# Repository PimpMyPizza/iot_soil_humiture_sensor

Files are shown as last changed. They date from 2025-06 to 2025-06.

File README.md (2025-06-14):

# Connected Humidity and Temperature Sensors

This is a simple MicroPython project to read soil humidity and temperature sensor data using a Raspberry Pi Pico W. It sends the data over MQTT to be integrated with [Home Assistant](https://www.home-assistant.io/).

## What You'll Need

- A Raspberry Pi Pico W (not tested on Pico W 2)
- A soil moisture/humidity sensor (I used an old HD-38 analog sensor)
- A DS18B20 temperature sensor (I used the waterproof version)
- A micro USB cable for power
- (Optional) An NPN transistor (e.g., BC337-40) to switch the moisture sensor off when not in use, extending its lifespan

## Wiring

| Component/Connection | Pico W Pin | Notes |
| --- | --- | --- |
| HD-38 + (VCC) | 3V3 (Pin 36) | Power supply for the moisture sensor |
| HD-38 - (GND) | Collector of NPN | Controlled ground connection |
| HD-38 AO (Analog Output) | GP26 / ADC0 (Pin 31) | Analog input for moisture level |
| NPN Emitter | Pico W GND | Common ground |
| NPN Base | GPIO15 (Pin 20) | Controls the moisture sensor power |
| DS18B20 VCC | GPIO17 (Pin 22) | Switched power for DS18B20 |
| DS18B20 GND | Pico W GND | Common ground |
| DS18B20 Data | GPIO16 (Pin 21) | One-wire data line |
| 4.7kΩ Pull-up Resistor | Between Data & VCC | Required for DS18B20 |

## Uploading the Code to the Pico W

1. Flash the MicroPython .uf2 file onto your Pico W, as described in the [official MicroPython documentation](https://micropython.org/download/RPI_PICO_W/).
2. Use mpremote (or another tool) to copy files and run the script:
```bash
mpremote connect /dev/ttyACM0 \
  fs mkdir src \
  fs cp src/*.py :src/ \
  fs mkdir res \
  fs cp res/*.tmpl :res/ \
  fs cp main.py :main.py
```

## Initial Device Setup

On first boot, the device cannot connect to Wi-Fi unless you’ve preconfigured settings in `src/constants.py`. It will enter Access Point mode and serve a configuration page at http://192.168.4.1.

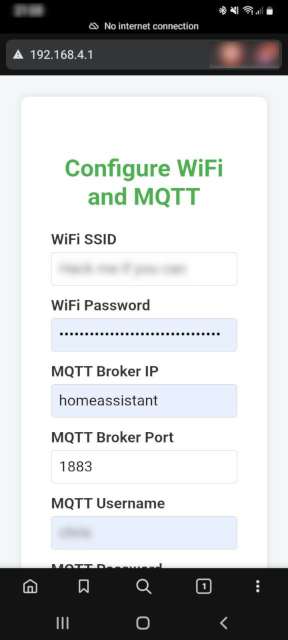
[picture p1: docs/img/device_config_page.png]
Device Configuration Page


1. Connect your phone or laptop to the device's Wi-Fi.
2. Open http://192.168.4.1 in a browser.
3. Enter/Adapt:
    - Wi-Fi SSID and password
    - MQTT broker address, username, and password
    - Measurement frequency
4. Click Save.

The device will remain in AP mode until it can successfully connect to Wi-Fi and the MQTT broker with valid credentials.

## Integrating with Home Assistant

Once connected, the device will send an MQTT discovery message.
1. In Home Assistant, go to Settings > Devices & Services.
2. In the Devices tab, a new device should appear.
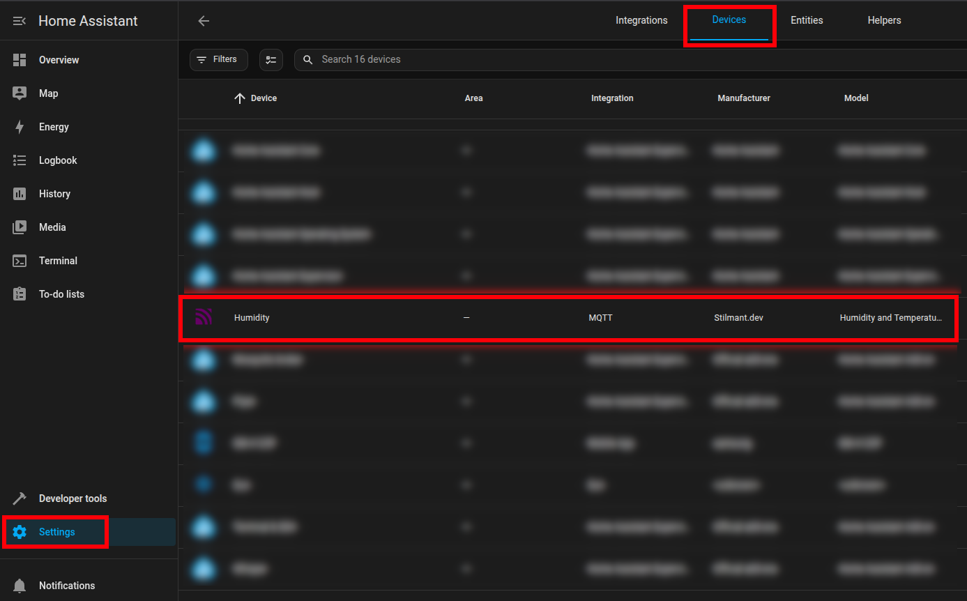
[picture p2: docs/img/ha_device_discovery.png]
Device Configuration Page

3. Click the device to view and add sensors to your dashboard.
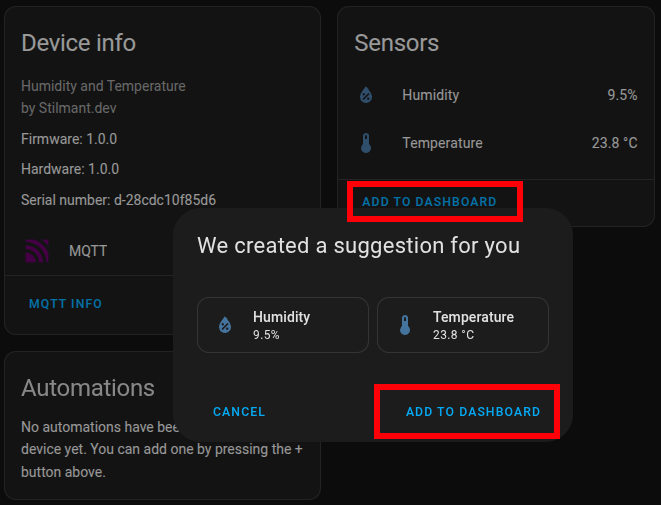
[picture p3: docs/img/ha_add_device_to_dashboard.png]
Device Configuration Page


And that’s it! Your soil humidity and temperature sensor is now connected to Home Assistant.

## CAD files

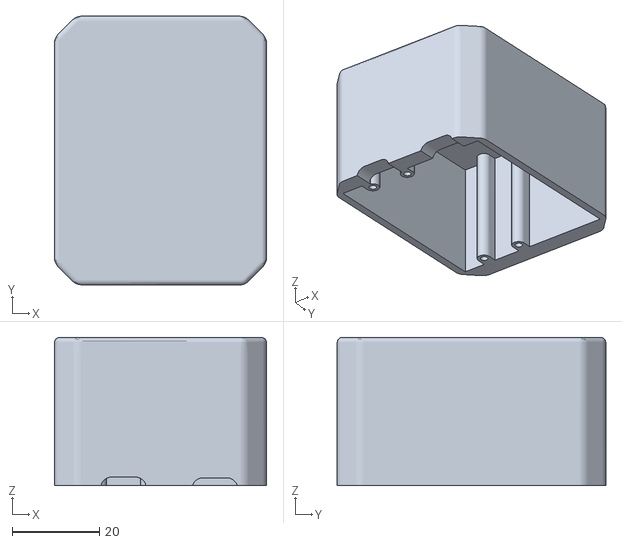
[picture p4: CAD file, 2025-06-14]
cad/case_top.stl
48.7 x 61.7 x 34.0

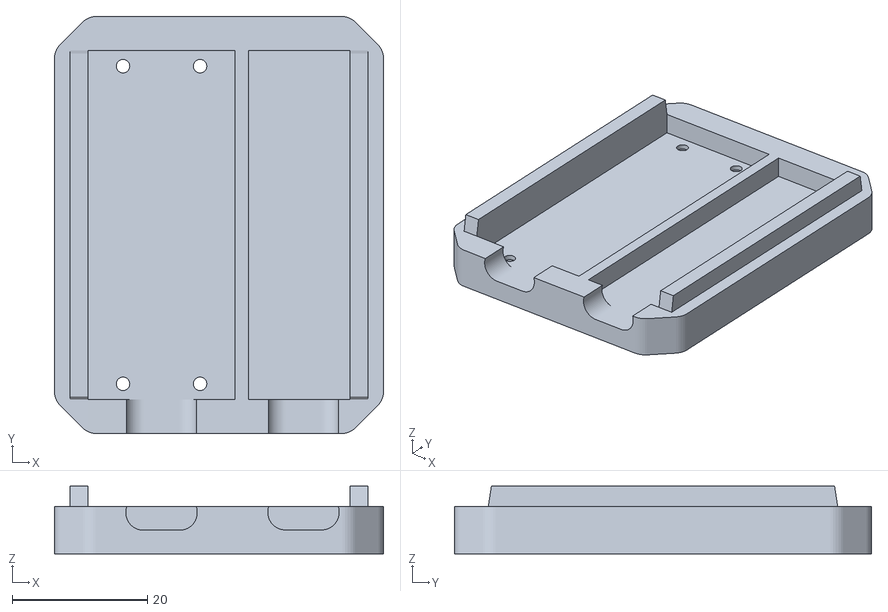
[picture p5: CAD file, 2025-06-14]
cad/case_bottom.stl
48.7 x 61.7 x 10.0

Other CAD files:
cad/case.blend

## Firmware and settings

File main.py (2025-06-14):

import time
import machine
from src.config import Config
from src import network
from src import mqtt
from src import soil_humidity
from src import temperature
from src.constants import (
    HUMIDITY_SWITCH_ON_OFF_PIN,
    TEMPERATURE_SWITCH_ON_OFF_PIN,
    PIN_ON,
    PIN_OFF,
)


def main():
    config = Config()
    config.load()
    print(f"Loaded config:\n", config.to_dict())

    if not config.valid() or not network.connect_to_wifi(config):
        # Invalid config or unable to connect to wifi: pico acts as an
        # access point until the user has adapted the wifi config. The
        # configuration page is accessible via http://192.168.4.1 and
        # the device reboots after the user saves the new change.
        network.start_ap_mode(config)

    # Let Home Assistant know which data is published and how.
    if not mqtt.send_discovery(config):
        # If the discovery failed, go into AP mode again. This could be
        # due to some invalid config, e.g. when user password is wrong,
        # leading to MQTT unauthorized. In that case, the user has to
        # re-enter the right password.
        # TODO: show error in config page to let user what happened.
        network.start_ap_mode(config)

    humidity_switch_on_off_pin = machine.Pin(
        HUMIDITY_SWITCH_ON_OFF_PIN,
        machine.Pin.OUT,
    )
    temperature_switch_on_off_pin = machine.Pin(
        TEMPERATURE_SWITCH_ON_OFF_PIN,
        machine.Pin.OUT,
    )

    while True:
        # Save time at which we started measuring to have more precise
        # sleep duration
        measurements_start = time.time()

        # Turn on sensors
        humidity_switch_on_off_pin.value(PIN_ON)
        temperature_switch_on_off_pin.value(PIN_ON)

        # Wait a few seconds for the sensor to stabilize their readings.
        # This is needed, e.g. for the capacitive humidity sensors to
        # heat up. If we don't wait, the humidity readings will be
        # overestimated.
        time.sleep(45)
        moisture_value = soil_humidity.read()
        temperature_value = temperature.read()

        try:
            mqtt.publish(
                config=config,
                topic=config.mqtt.device_state_topic,
                payload={
                    "state": "ON",
                    "timestamp": time.time(),
                    "temperature": temperature_value,
                    "humidity": moisture_value,
                },
                retain=True,
            )
        except Exception as e:
            print("Failed to publish MQTT. Error: ", e)

        # Turn off sensors and sleep until next measurement
        humidity_switch_on_off_pin.value(PIN_OFF)
        temperature_switch_on_off_pin.value(PIN_OFF)

        # Adapt time to sleep (user-defined period minus measurements
        # duration).
        meas_duration = time.time() - measurements_start
        sleep_time = (86400 / config.measurements_per_day) - meas_duration
        print("Deactivated sensor.")
        print(f"Going to sleep now for {round(sleep_time)} seconds.")
        # TODO: use actual deepsleep functionality of pico W instead of
        #   time sleep
        time.sleep(sleep_time)


if __name__ == "__main__":
    main()

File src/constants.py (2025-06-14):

# Change these only if you want to skip the setup of the device via the AP/HTTP server
# and directly use your own settings for your home. If left unchanged, you'll be able
# to edit these by connecting to the pico W AP and connect to http://192.168.4.1 at
# initial boot.

# Default Access Point settings
AP_SSID = "Soil Sensor"
AP_PASSWORD = "password"

# Default wifi settings
DEFAULT_WIFI_SSID = "Your-Wifi SSID"
DEFAULT_WIFI_PASSWORD = ""

# Default MQTT settings
UNDEFINED_OBJECT_ID = "<undefined>"
DEFAULT_MQTT_DISCOVERY_ENABLED = True
DEFAULT_MQTT_DEVICE_STATE_TOPIC = f"my/plant/{UNDEFINED_OBJECT_ID}/state"
# See https://www.home-assistant.io/integrations/mqtt/#discovery-topic
DEFAULT_MQTT_DISCOVERY_TOPIC = f"homeassistant/device/{UNDEFINED_OBJECT_ID}/config"
DEFAULT_MQTT_BROKER_NAME = "homeassistant"
DEFAULT_MQTT_BROKER_PORT = 1883
DEFAULT_MQTT_USERNAME = ""
DEFAULT_MQTT_PASSWORD = ""

# Default sensor readings frequency per day.
DEFAULT_MEASUREMENTS_PER_DAY = 24

# 1-wire temperature data sensor pin
TEMPERATURE_DATA_PIN = 16
# GPIO pin used to turn on/off the temperature sensor
TEMPERATURE_SWITCH_ON_OFF_PIN = 17

# GPIO pin used to read soil humidity sensor data
SOIL_HUMIDITY_SENSOR_PIN = 26
# GPIO pin used to deactivate humidity sensor in deepsleep mode
HUMIDITY_SWITCH_ON_OFF_PIN = 15

PIN_ON = 1
PIN_OFF = 0
